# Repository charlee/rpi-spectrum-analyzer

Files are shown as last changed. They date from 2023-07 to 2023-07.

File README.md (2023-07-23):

Spectrum Analyzer with Raspberry Pi Pico
=========================================

I bought some RGB LED screens pretty long ago and decided to make something with them.
And this spectrum analyzer is the result.

See the following video for demo. 

Demo video (https://youtu.be/qcwmG_PlZZ8)

## Hardware

See [hardware](hardware/) for details.

## Code for Raspberry Pi Pico

- `pixelmatrix.py`: Pixel matrix driver. It uses PIO to drive the LED matrix.
- `code.py`: The main program. It reads the audio signal from ADC pin, uses FFT to convert the signal to spectrum, and then send it to the LED matrix driver.
- `lib/ds1302.py`: DS1302 RTC driver. It is used to display the time on the LED matrix.
- `setup_rtc.py`: A helper to use DS1302 as the time source.

See [rp2040](rp2040/) for details.

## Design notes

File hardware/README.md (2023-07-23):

Hardware for Spectrum Analyzer with Raspberry Pi Pico
=====================================================

I bought some RGB LED matrix pretty long ago. It looks like this:

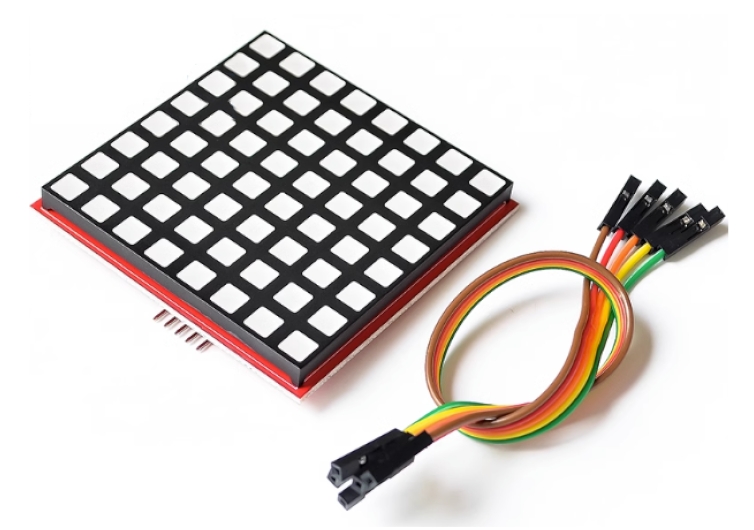
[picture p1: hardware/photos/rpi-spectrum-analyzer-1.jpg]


According to the seller, this is an 8x8 RGB LED matrix driven by 74HC595, and has SPI support.
The module provide 5 pins: VCC, GND, CLK, MOSI, and CS, which is the standard SPI interface.
The seller provided a sample program for Raspberry Pi:

```c
#include <stdio.h>
#include <wiringPi.h>
#include <wiringPiSPI.h>
#include <stdint.h>
 
#define RED_DATA 0
#define BLUE_DATA 1
#define GREEN_DATA 2
 
int main(void)
{
  static uint8_t data[4] = {0x0,0x0,0x0,0x0};
  wiringPiSetup();
  wiringPiSPISetup(0,500000);
  while(1)
  {
    static uint8_t heart[8] = {0x00, 0x66, 0xFF, 0xFF, 0xFF, 0x7E, 0x3C, 0x18};
    int j;
    int x=2;
    for ( j=0;j<8;j++)
    {
      data[0] = ~heart[j];
      data[2] = 0xFF;
      data[1] = 0xFF;
      data[3] = 0x01 << j ;
      wiringPiSPIDataRW(0,data,sizeof(data));
      delay(x);
    };
  };
}
```

According to the code, I assume the data should be sent in the following format:

```
row0: [0xRR 0xBB 0xGG 0b00000001]
row1: [0xRR 0xBB 0xGG 0b00000010]
row2: [0xRR 0xBB 0xGG 0b00000100]
row3: [0xRR 0xBB 0xGG 0b00001000]
row4: [0xRR 0xBB 0xGG 0b00010000]
row5: [0xRR 0xBB 0xGG 0b00100000]
row6: [0xRR 0xBB 0xGG 0b01000000]
row7: [0xRR 0xBB 0xGG 0b10000000]
```

where `0xRR` is the red data, `0xBB` is the blue data, `0xGG` is the green data.
Each byte represents one row, and the 4th byte indicates which row these bytes are for.

So my first step is to write a program to drive the LED matrix. I used Raspberry Pi Pico and CircuitPython for this project. After some try and error, I successfully lighted up the LED matrix.

Unfortunately, after some exploration, I noticed that there was a flaw in the LED matrix: the red, blue, and green LED in one pixel share the same resistor. Since red LED has lower voltage drop than blue and green LED, the red LED will take most of the current and the blue and green LED will be very dim, if the bytes for R, G, B are sent simultaneously. This means you won't be able to show colors other than Red, Green, and Blue.

In order to display other colors, I have to use the scanning trick: send one color one time and set other two colors to `0x00`, then send the second color and set other two colors to `0x00`, and so on. This way, only one color will be lit at one time, so red, gree, and blue LED will have the same brightness.

It's not easy to achieve this with CircuitPython bitbanging, since you have to send the data fast enough to prevent blinking, and CircuitPython is just not fast enough. I have to employ the PIO feature to achieve this. I wrote a PIO program to drive the LED matrix, and it works pretty well:

```
    .program quad_led_matrix_spi
    .side_set 1

    set pins, 0x7
    set x, 31
loop1:
    out pins, 1       side 0
    jmp x--, loop1    side 1
    
    set pins, 0xb
    set x, 31
loop2:
    out pins, 1       side 0
    jmp x--, loop2    side 1

    set pins, 0xd
    set x, 31
loop3:
    out pins, 1       side 0
    jmp x--, loop3    side 1

    set pins, 0xe
    set x, 31
loop4:
    out pins, 1       side 0
    jmp x--, loop4    side 1
```

This PIO assembly uses `set` pin for `CS`, `sideset` for `CLK`, and `out` pins for `MOSI`.
It simply reads the data from input buffer and send it to 4 LED matrix, one by one, controlled by `x` register. Then, use CircuitPython to arrange the data and send it to the input buffer of the PIO program. The PIO program will send the data to the LED matrix.

With [this program](../rp2040/pixelmatrix.py), I can display any color I want. Here is a picture of all pixels showing white:

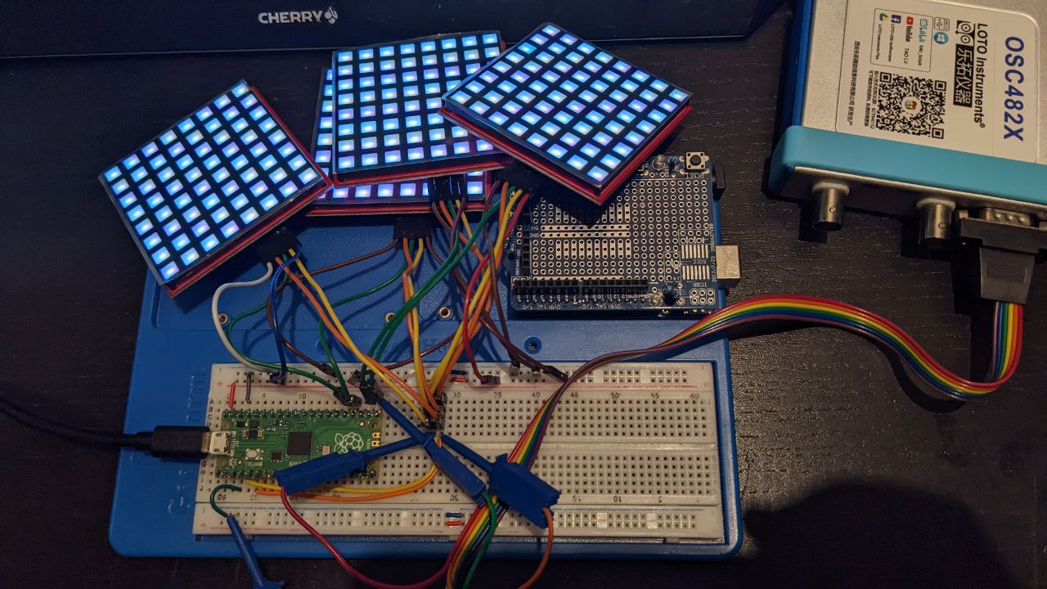
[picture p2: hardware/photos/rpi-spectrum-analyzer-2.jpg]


I also 3D printed a frame to hold 4 screens together:

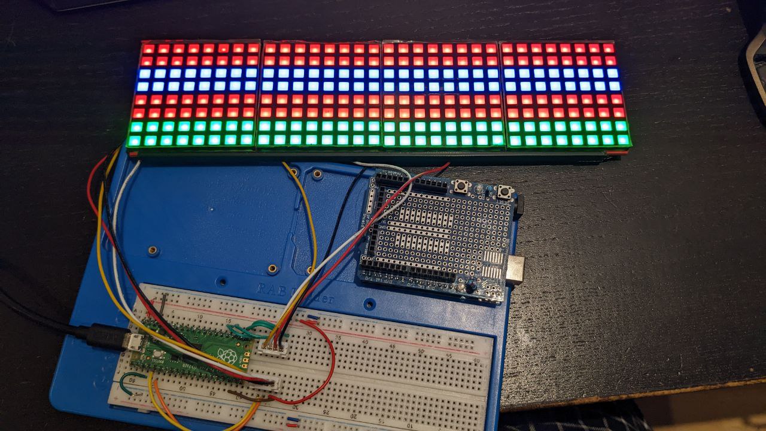
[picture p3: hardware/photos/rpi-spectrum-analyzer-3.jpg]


In order to make a spectrum analyzer, I need to capture the input audio signal and send it to the ADC pin of the Raspberry Pi Pico. I need an amplifier circuit to receive the audio signal, and then use an OP Amp to scale it to the range of 0-3.3V. I ended up with the following schematic:

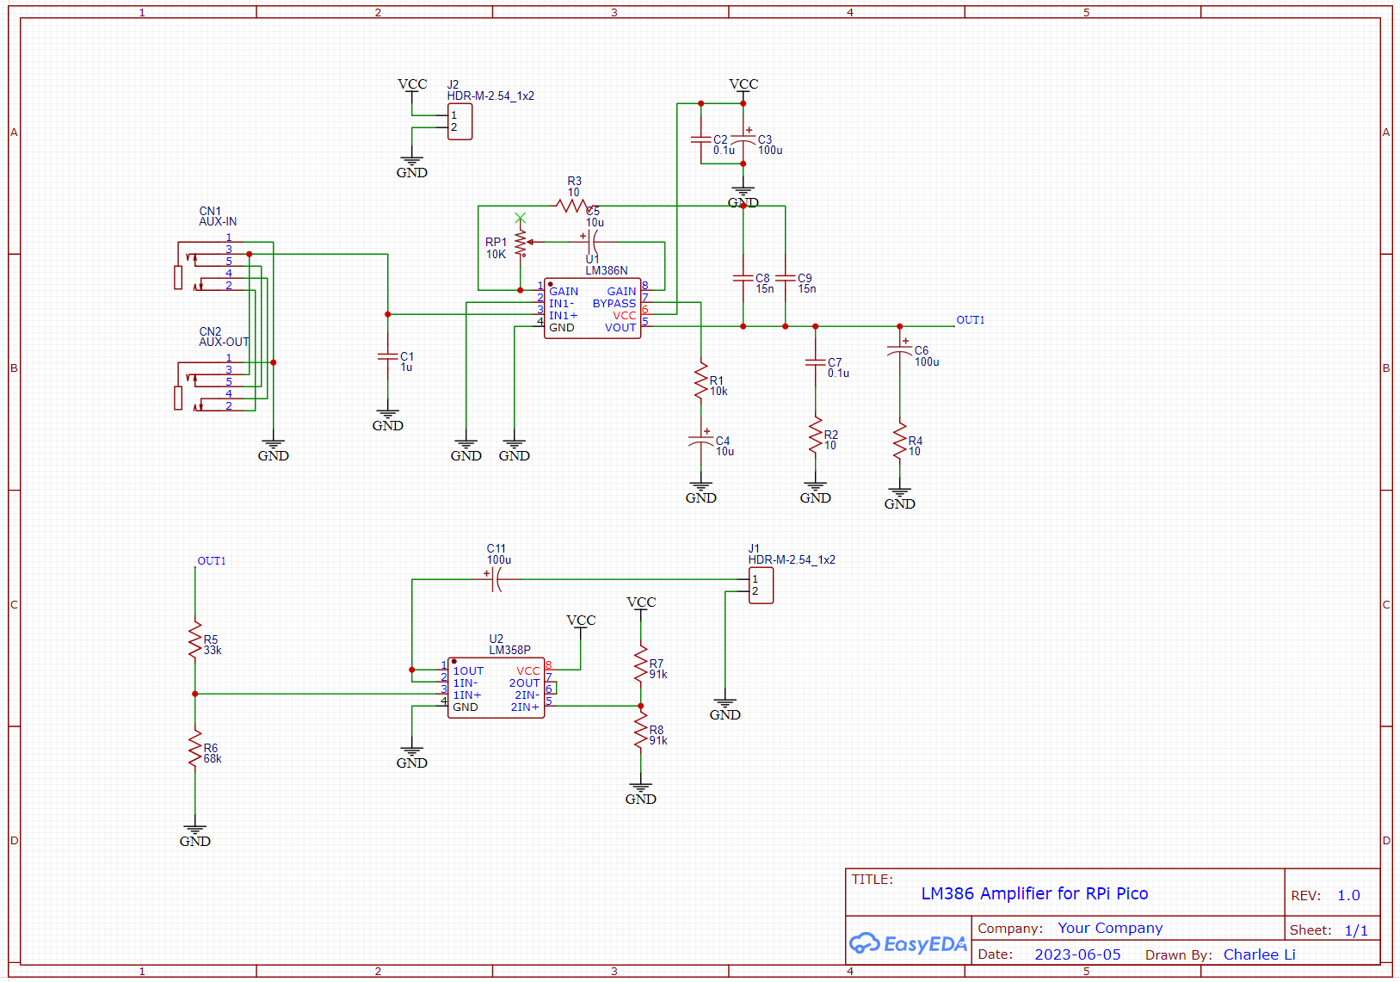
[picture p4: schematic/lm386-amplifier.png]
Amplifier Schematic


The upper part uses LM386 to amplify the audio signal to the range of 0-5V. RP1 is used to adjust the gain. The lower part uses OP Amp to scale the signal to the range of 0-3.3V, so that it can be safely picked up by RPi Pico.

Here is the breadboard:

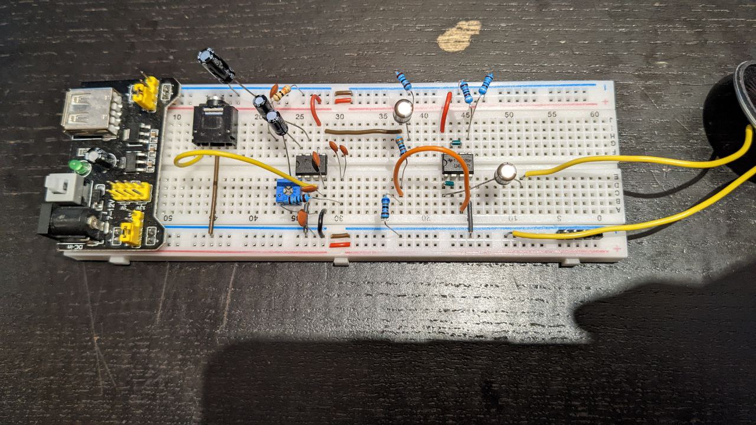
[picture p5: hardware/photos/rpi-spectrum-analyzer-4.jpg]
Amplifier Breadboard


And here is the PCB:

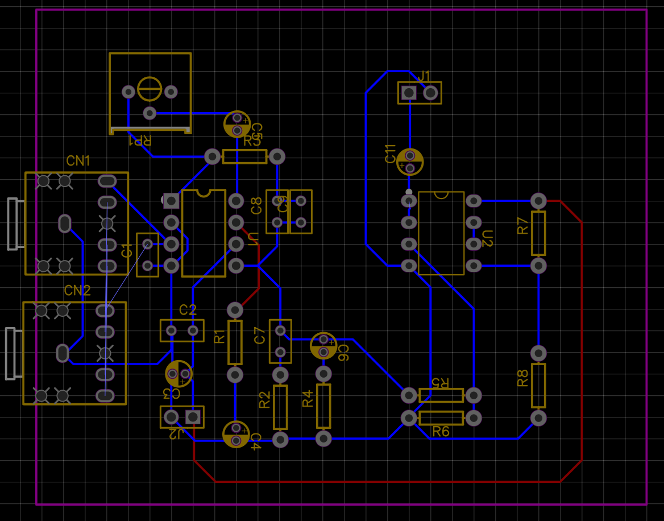
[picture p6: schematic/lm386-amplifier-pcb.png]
Amplifier PCB


The soldered PCB looks like this:

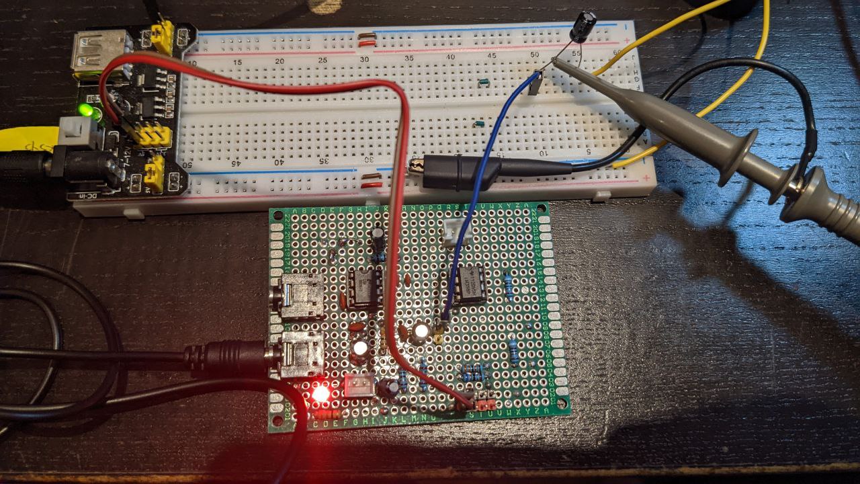
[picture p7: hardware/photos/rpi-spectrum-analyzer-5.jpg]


Now it's time to make the spectrum analyzer. A spectrum analyzer is simply a FFT (Fast Fourier Transform) of the audio signal. I used the [FFT library from ulab](https://micropython-ulab.readthedocs.io/en/latest/numpy-fft.html). The code can be found [here](../rp2040/code.py).

To make it more useful, I also embedded a DS1302 RTC module to display the current time.
Note that Raspberry Pi Pico does not have a RTC module, so you cannot read the current time using `datetime` package, when the Pico is not connected to a computer. I have to use a DS1302 RTC module with a CR2032 battery to keep the time.

The [DS1302 library](https://github.com/odeevee/DS1302_CircuitPython) has a bug that it does not set the year correctly, so I have to manually fix the bug and include [the source code](../rp2040/lib/ds1302.py) in the lib directory.

Here is a picture of all components connected together:

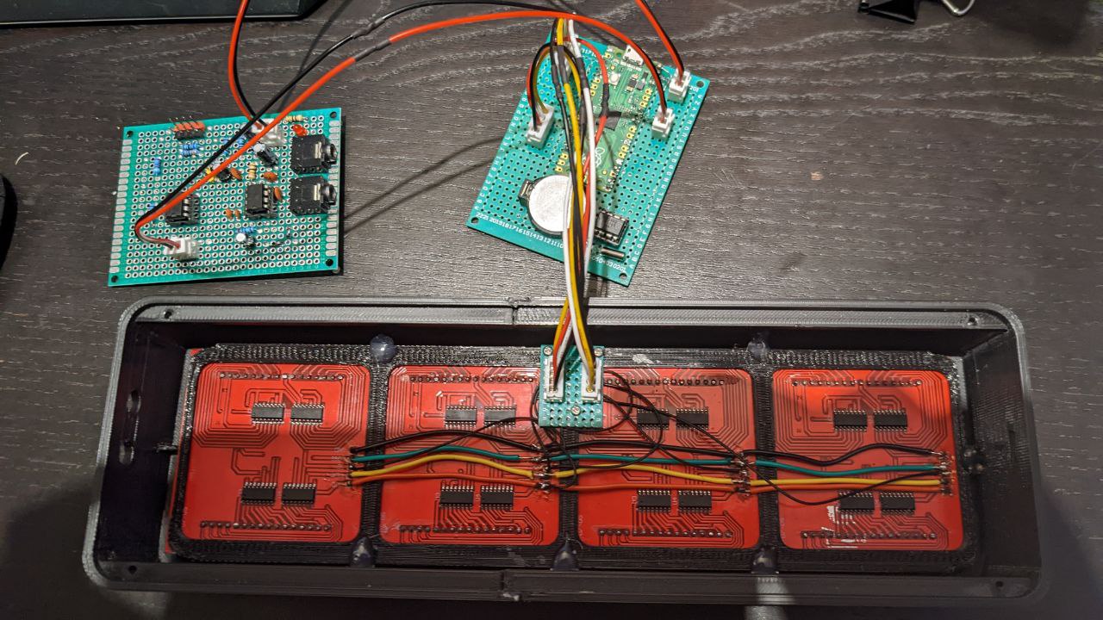
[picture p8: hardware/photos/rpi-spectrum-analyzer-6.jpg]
All components


I printed a back cover to hold the RPi Pico and the amplifier:

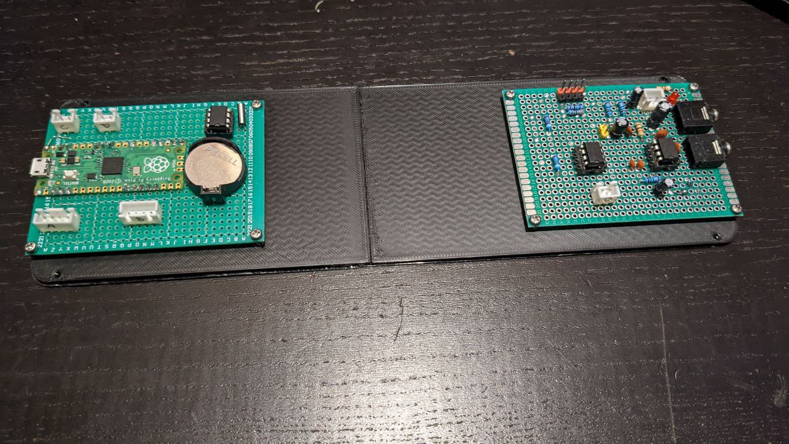
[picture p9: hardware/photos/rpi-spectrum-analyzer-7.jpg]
Back cover


And a case to hold the screen:

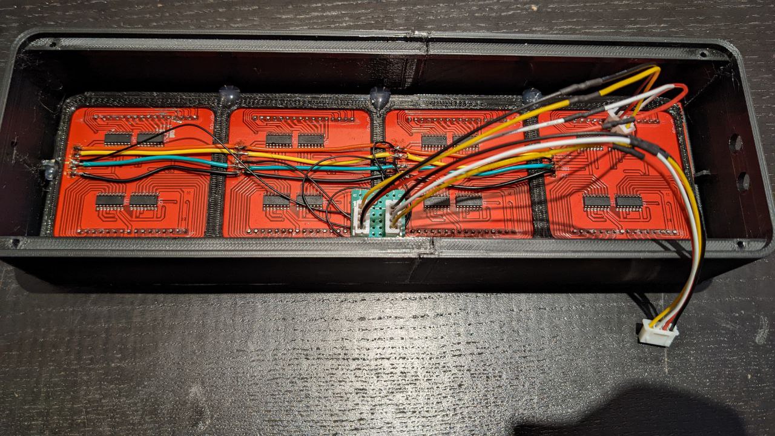
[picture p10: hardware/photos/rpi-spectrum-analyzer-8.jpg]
Case


Case and back cover together:

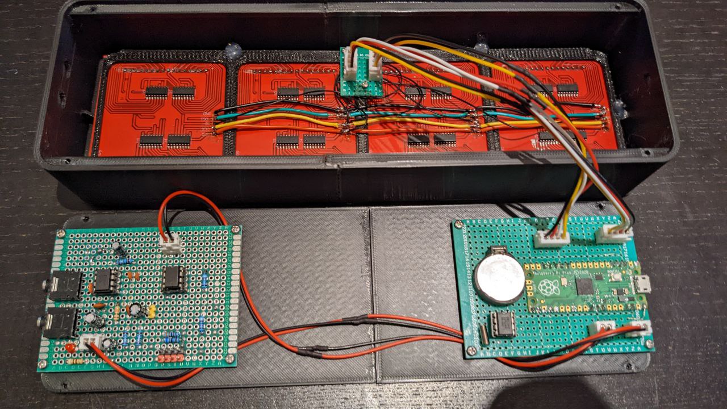
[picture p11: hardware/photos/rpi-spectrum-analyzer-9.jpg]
Case and back cover


Finally, glue a piece of black acrylic to the front of the case:

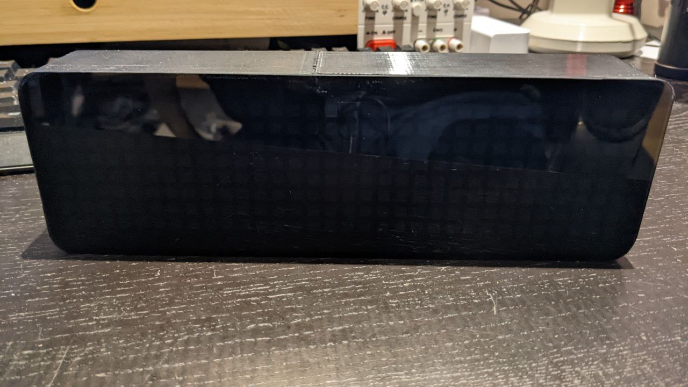
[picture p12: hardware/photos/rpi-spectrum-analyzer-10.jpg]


When no signal input, it will display the current time:

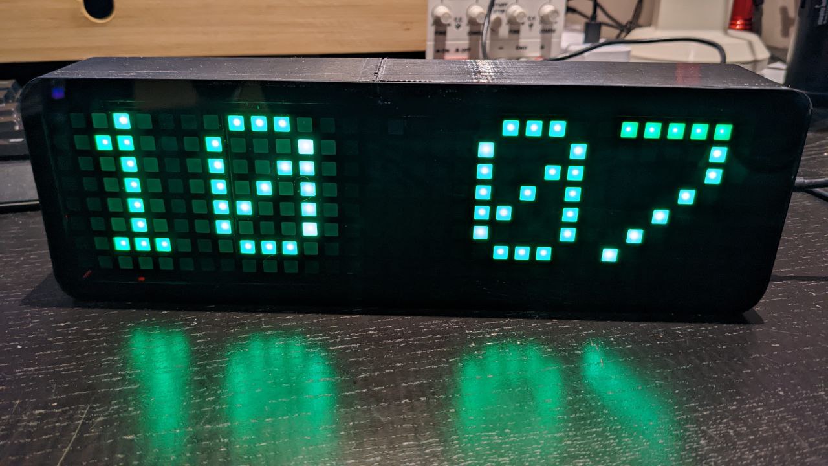
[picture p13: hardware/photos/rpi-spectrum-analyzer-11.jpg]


When there is signal input, it will display the spectrum:

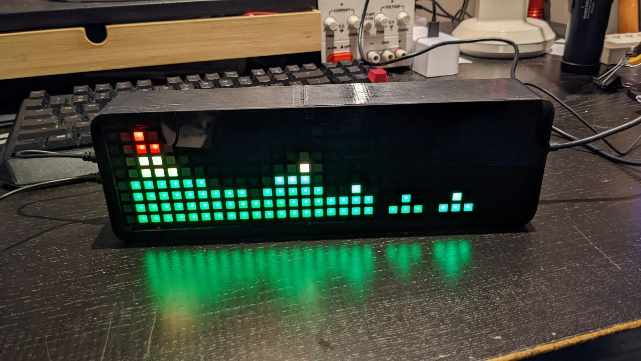
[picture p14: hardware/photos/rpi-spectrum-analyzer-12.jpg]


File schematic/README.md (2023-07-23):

Schematic
=============

The schemataic of the LM386 amplifier: 

Schematic

The PCB of the LM386 amplifier:

PCB

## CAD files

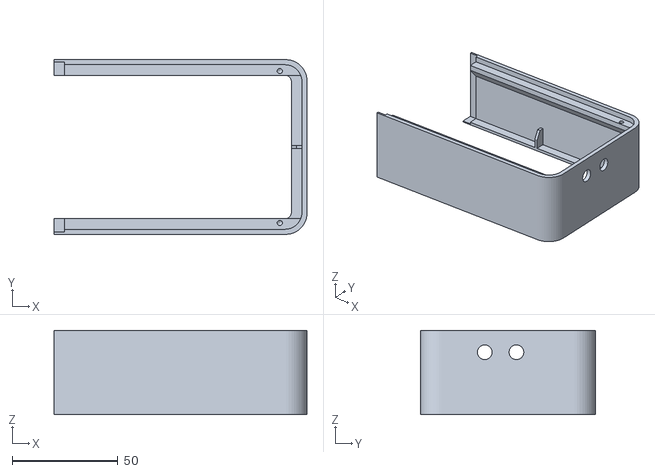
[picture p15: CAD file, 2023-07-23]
cad/CaseTop-2.stl
119.9 x 82.8 x 40.0

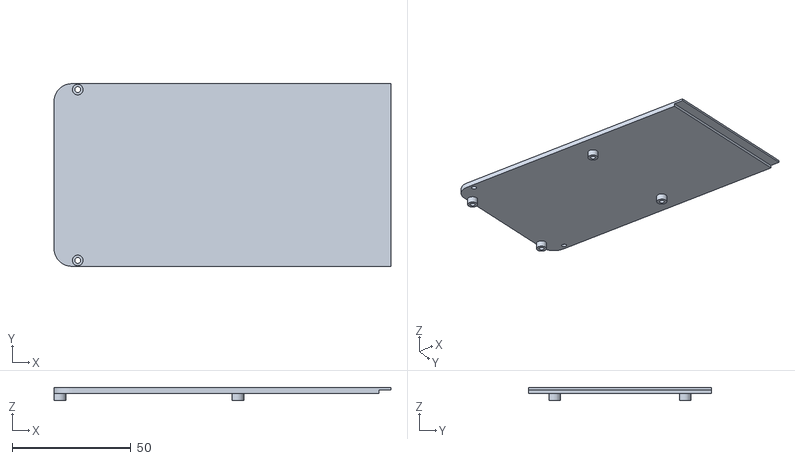
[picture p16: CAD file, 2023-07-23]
cad/CaseBottom-1.stl
142.0 x 77.0 x 5.40

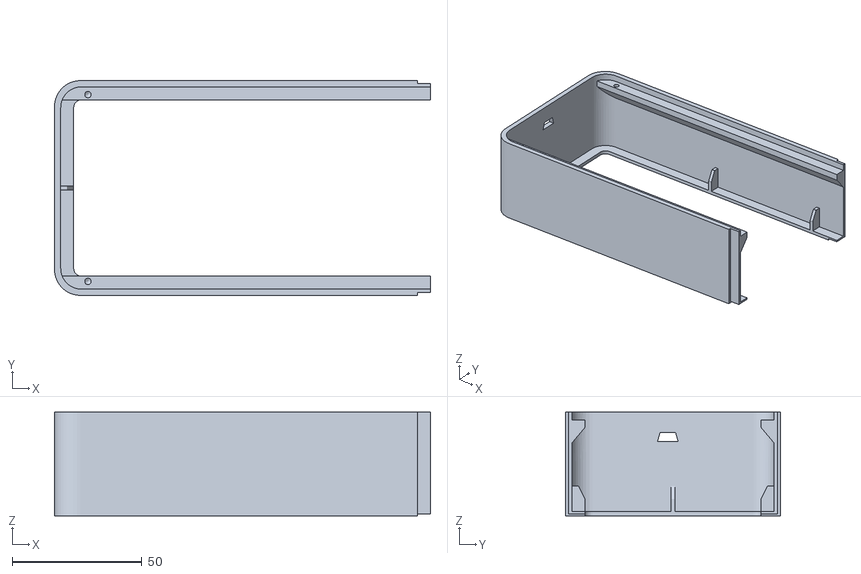
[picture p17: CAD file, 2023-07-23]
cad/CaseTop-1.stl
144.9 x 82.8 x 40.0

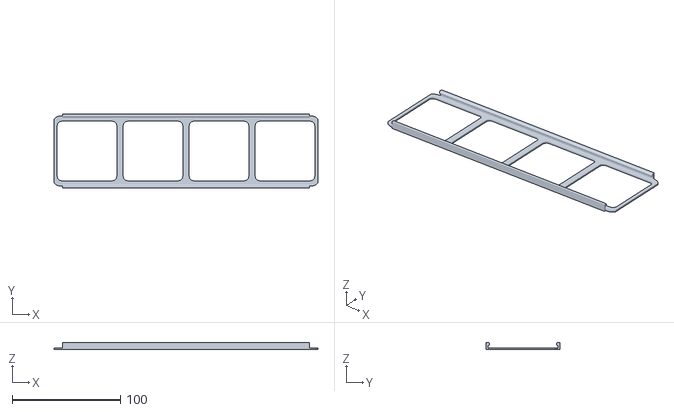
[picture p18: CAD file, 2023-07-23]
cad/ScreenHolder.stl
244.0 x 68.2 x 6.60

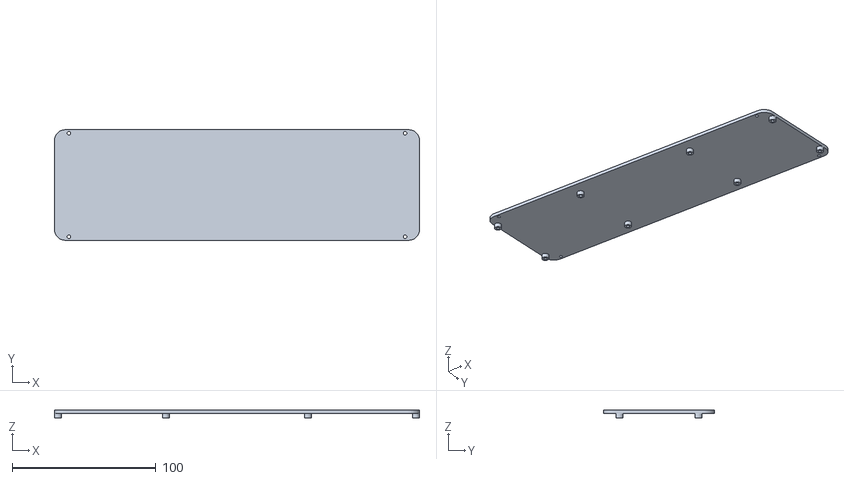
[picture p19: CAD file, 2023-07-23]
cad/CaseBottom.stl
254.0 x 77.0 x 5.40

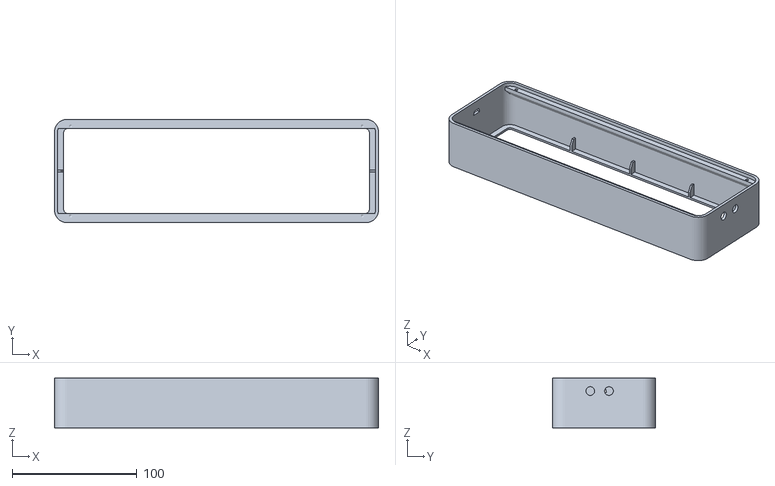
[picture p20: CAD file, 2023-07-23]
cad/CaseTop.stl
259.8 x 82.8 x 40.0

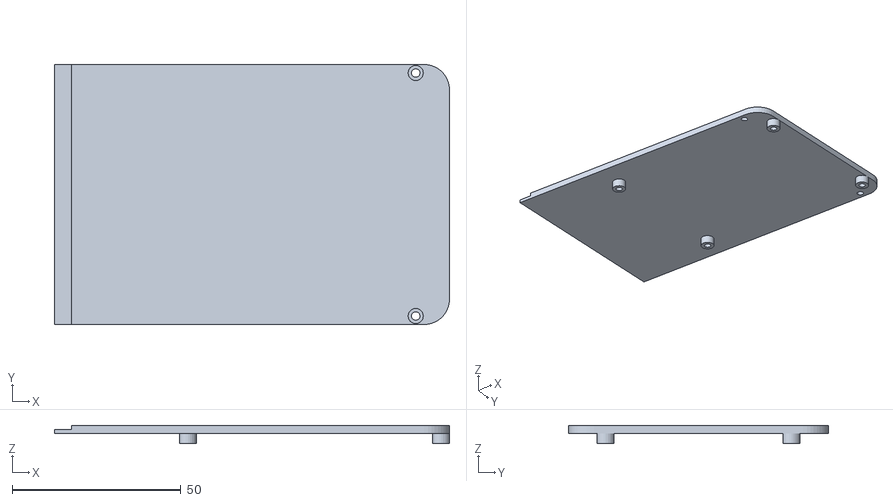
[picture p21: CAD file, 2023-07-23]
cad/CaseBottom-2.stl
117.0 x 77.0 x 5.40

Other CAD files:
cad/8x32display v18.f3d

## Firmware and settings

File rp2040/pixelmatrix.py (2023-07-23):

import array
import rp2pio
import adafruit_pioasm
import adafruit_framebuf as framebuf

class Color:
    BLACK   = (0, 0, 0)
    RED     = (1, 0, 0)
    GREEN   = (0, 1, 0)
    BLUE    = (0, 0, 1)
    YELLOW  = (1, 1, 0)
    CYAN    = (0, 1, 1)
    MAGENTA = (1, 0, 1)
    WHITE   = (1, 1, 1)
    
class Dimension:
    SIZE_X = 4
    SIZE_Y = 1
    MATRIX_SIZE = 8
    WIDTH = MATRIX_SIZE * SIZE_X
    HEIGHT = MATRIX_SIZE * SIZE_Y
    
    
class PSFormat:
    """Pixel format for the pixel screen.
    """

    @staticmethod
    def set_pixel(framebuf, x, y, color):
        index = (y * framebuf.width + x) // 8
        offset = x & 0x07
        framebuf.buf[index] = (framebuf.buf[index] & ~(0x80 >> offset)) | ((color & 0x01) << (7 - offset))

    @staticmethod
    def get_pixel(framebuf, x, y):
        index = (y * framebuf.width + x) // 8
        offset = x & 0x07
        return (framebuf.buf[index] >> (7 - offset)) & 0x01

    @staticmethod
    def fill(framebuf, color):
        if color:
            fill = 0xff
        else:
            fill = 0x00

        for i in range(len(framebuf.buf)):
            framebuf.buf[i] = fill

    @staticmethod
    def fill_rect(framebuf, x, y, width, height, color):
        for _x in range(x, x + width):
            offset = _x & 0x07
            for _y in range(y, y + height):
                index = (_y * framebuf.width + _x) // 8
                if color:
                    framebuf.buf[index] |= 0x80 >> offset
                else:
                    framebuf.buf[index] &= ~(0x80 >> offset)


class PixelScreenFrameBuf:
    """The FrameBuf for the 32x8 pixel screen.
    """

    def __init__(self):
        bufsize = int(Dimension.WIDTH / 8 * Dimension.HEIGHT)
        
        # since the LED matrx used by the screen shares one resistor among all R/G/B LEDs,
        # we won't be able to light R with G or B due to R-LED has a way smaller voltage drop than G/B.
        # we have to use scanning to show R and G/B alternatively to simulate colors.
        self._buf_r = bytearray(bufsize)
        self.fb_r = framebuf.FrameBuffer(self._buf_r, Dimension.WIDTH, Dimension.HEIGHT)
        self._buf_g = bytearray(bufsize)
        self.fb_g = framebuf.FrameBuffer(self._buf_g, Dimension.WIDTH, Dimension.HEIGHT)
        self._buf_b = bytearray(bufsize)
        self.fb_b = framebuf.FrameBuffer(self._buf_b, Dimension.WIDTH, Dimension.HEIGHT)
        
        self.fb_r.format = PSFormat()
        self.fb_g.format = PSFormat()
        self.fb_b.format = PSFormat()


    def get_data(self):
        bufsize = int(Dimension.WIDTH / 8 * Dimension.HEIGHT)
        data = array.array('L', [0] * bufsize * 2)

        for i in range(bufsize):
            # chip select byte
            cs = (i // Dimension.SIZE_X) % Dimension.MATRIX_SIZE
            data[i] = (0b10000000 >> cs) << 24 | 0x00ffff00 | (self._buf_r[i] ^ 0xff)

        for i in range(bufsize):
            # chip select byte
            cs = (i // Dimension.SIZE_X) % Dimension.MATRIX_SIZE
            data[bufsize + i] = (0b10000000 >> cs) << 24 | 0x000000ff | (self._buf_g[i] ^ 0xff) << 16 | (self._buf_b[i] ^ 0xff) << 8

        return data

    def pixel(self, x, y, color):
        """Set the pixel at position (x, y) to the given color.
        """
        self.fb_r.pixel(x, y, color[0])
        self.fb_g.pixel(x, y, color[1])
        self.fb_b.pixel(x, y, color[2])
        
    def fill(self, color):
        """Fill the screen with the given color.
        """
        self.fb_r.fill(color[0])
        self.fb_g.fill(color[1])
        self.fb_b.fill(color[2])

    def rect(self, x, y, width, height, color):
        self.fb_r.rect(x, y, width, height, color[0])
        self.fb_g.rect(x, y, width, height, color[1])
        self.fb_b.rect(x, y, width, height, color[2])

    def fill_rect(self, x, y, width, height, color):
        self.fb_r.fill_rect(x, y, width, height, color[0])
        self.fb_g.fill_rect(x, y, width, height, color[1])
        self.fb_b.fill_rect(x, y, width, height, color[2])

    def hline(self, x, y, width, color):
        self.fb_r.hline(x, y, width, color[0])
        self.fb_g.hline(x, y, width, color[1])
        self.fb_b.hline(x, y, width, color[2])

    def vline(self, x, y, height, color):
        self.fb_r.vline(x, y, height, color[0])
        self.fb_g.vline(x, y, height, color[1])
        self.fb_b.vline(x, y, height, color[2])

    def line(self, x1, y1, x2, y2, color):
        self.fb_r.line(x1, y1, x2, y2, color[0])
        self.fb_g.line(x1, y1, x2, y2, color[1])
        self.fb_b.line(x1, y1, x2, y2, color[2])

    def circle(self, center_x, center_y, radius, color):
        self.fb_r.circle(center_x, center_y, radius, color[0])
        self.fb_g.circle(center_x, center_y, radius, color[1])
        self.fb_b.circle(center_x, center_y, radius, color[2])

    def scroll(self, dx, dy):
        self.fb_r.scroll(dx, dy)
        self.fb_g.scroll(dx, dy)
        self.fb_b.scroll(dx, dy)

    def text(self, string, x, y, color):
        self.fb_r.text(string, x, y, color[0])
        self.fb_g.text(string, x, y, color[1])
        self.fb_b.text(string, x, y, color[2])



"""
PIO assmebly code for driving the 4-LED-Matrix screen
"""
quad_led_matrix_spi = """
    .program quad_led_matrix_spi
    .side_set 1

    set pins, 0x7
    set x, 31
loop1:
    out pins, 1       side 0
    jmp x--, loop1    side 1
    
    set pins, 0xb
    set x, 31
loop2:
    out pins, 1       side 0
    jmp x--, loop2    side 1

    set pins, 0xd
    set x, 31
loop3:
    out pins, 1       side 0
    jmp x--, loop3    side 1

    set pins, 0xe
    set x, 31
loop4:
    out pins, 1       side 0
    jmp x--, loop4    side 1
"""


class PixelScreen:
    def __init__(self, clk, mosi, first_cs, freq=1_000_000):
        assembled = adafruit_pioasm.assemble(quad_led_matrix_spi)
        self.sm = rp2pio.StateMachine(assembled, frequency=freq,
                                      first_out_pin=mosi,
                                      first_set_pin=first_cs,
                                      set_pin_count=Dimension.SIZE_X,
                                      first_sideset_pin=clk,
                                      auto_pull=True,
                                     )

        self.fb = PixelScreenFrameBuf()

    def show(self):
        data = self.fb.get_data()
        self.sm.background_write(loop=data)


# test code
if __name__ == '__main__':
    import board
    import time
    screen = PixelScreen(clk=board.GP2, mosi=board.GP3, first_cs=board.GP10)
    x = 1
    y = 1
    
    while True:
        screen.fb.fill(Color.BLACK)
        screen.fb.text('Hello, world', x, 0, Color.RED)
#         screen.fb.pixel(x, y, Color.RED)
#         screen.fb.fill_rect(0, 0, x, y, Color.GREEN)
#         screen.fb.line(0, 0, x, y, Color.YELLOW)

        # color test
#         screen.fb.fill_rect(0, 0, 8, 4, Color.RED)
#         screen.fb.fill_rect(8, 0, 8, 4, Color.GREEN)
#         screen.fb.fill_rect(16, 0, 8, 4, Color.BLUE)
#         screen.fb.fill_rect(24, 0, 8, 4, Color.BLACK)
#         screen.fb.fill_rect(0, 4, 8, 4, Color.YELLOW)
#         screen.fb.fill_rect(8, 4, 8, 4, Color.CYAN)
#         screen.fb.fill_rect(16, 4, 8, 4, Color.MAGENTA)
#         screen.fb.fill_rect(24, 4, 8, 4, Color.WHITE)
#         
        screen.show()
        time.sleep(0.5)
        x -= 1



        

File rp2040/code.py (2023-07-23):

import setup_rtc
import time
import math
import board
import analogio
import array
from math import sqrt
from ulab import numpy as np
import ulab

from pixelmatrix import PixelScreen, Color, Dimension


SIZE_X = 4
SIZE_Y = 1
MATRIX_SIZE = 8
WIDTH = SIZE_X * MATRIX_SIZE
HEIGHT = SIZE_Y * MATRIX_SIZE
SAMPLE_SIZE = WIDTH * 2

NOISE = 5000

MODE_CLOCK = 0
MODE_SPECTRUM = 1
MODE_TEST = 2


adc = analogio.AnalogIn(board.A0)


def sample():
    '''Sample the ADC.'''
    buffer = np.zeros(SAMPLE_SIZE)
    for i in range(SAMPLE_SIZE):
        buffer[i] = adc.value
        time.sleep(0.00001)
    
    # remove DC component
    mean = sum(buffer) / SAMPLE_SIZE
    buffer = buffer - mean
    
    # windowing
    for i in range(SAMPLE_SIZE / 2):
        factor = 0.54 - 0.46 * math.cos(2 * math.pi * i / (SAMPLE_SIZE-1))
        buffer[i] *= factor
        buffer[SAMPLE_SIZE - i - 1] *= factor
    
    
    # compute fft and magnitude
    freqs = ulab.utils.spectrogram(buffer)
    
    # filter noise
    for i in range(len(freqs)):
        if freqs[i] < NOISE:
            freqs[i] = 0
    
    return freqs


screen = PixelScreen(clk=board.GP2, mosi=board.GP3, first_cs=board.GP10)
mode = MODE_CLOCK

mode_switch_counter = 10000

while True:
    screen.fb.fill(Color.BLACK)

    if mode == MODE_CLOCK:
        # test if need to switch mode
        freqs = sample()
        if any(f > 1 for f in freqs):
            mode_switch_counter -= 1000
        if mode_switch_counter <= 0:
            mode = MODE_SPECTRUM
            mode_switch_counter = 10000
        
        # setup clock
        tm = time.localtime()
        s = (time.monotonic_ns() // 500_000_000) % 2
        if s == 1:
            colon = ':'
        else:
            colon = ' '
        
        text = f'{tm.tm_hour:2d}{colon}{tm.tm_min:02d}'
        screen.fb.text(text, 1, 0, Color.GREEN)
        
    elif mode == MODE_SPECTRUM:
        # setup spectrum analyzer
        
        # sample
        freqs = sample()
        
        # test if need to switch mode
        if all(f <= 1 for f in freqs):
            mode_switch_counter -= 100
        if mode_switch_counter <= 0:
            mode = MODE_CLOCK
            mode_switch_counter = 10000
        
        # draw spectrum
        lo, hi = min(freqs), max(freqs)
        hi = max(hi, NOISE)
        freqs = (freqs - lo) * Dimension.HEIGHT / (hi - lo)
        
        for x in range(Dimension.WIDTH):
            f = (freqs[x // 2] + freqs[(x + 1) // 2]) / 2
            for y in range(f):
                if y < 4:
                    color = Color.GREEN
                elif y < 6:
                    color = Color.YELLOW
                else:
                    color = Color.RED
                screen.fb.pixel(x, Dimension.HEIGHT - 1 - y, color)
                
    screen.show()
    
    if mode == MODE_SPECTRUM:
        time.sleep(0.0001)
    else:
        time.sleep(0.1)
